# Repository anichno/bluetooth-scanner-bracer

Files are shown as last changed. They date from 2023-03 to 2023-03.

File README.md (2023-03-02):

# Docs
[Design Overview](docs/Design%20Overview.md)

[System Architecture](docs/System%20Architecture.md)

[Part List](docs/Part%20List.md)

[Milestones](docs/Milestones.md)

[Library Selection](docs/Library%20Selection.md)

[Links](docs/Links.md)

# Setup
- Setup vagrant (Virtualbox Provider)
	```bash
	# go grab a coffee or whatever, this will take a while
	vagrant up
	
	# get ssh-config and add it to your own
	vagrant ssh-config
	```
- Connect with VS Code, [remote-ssh](https://marketplace.visualstudio.com/items?itemName=ms-vscode-remote.remote-ssh) plugin
- Workspace will be in `/home/vagrant/project`
- Connect ESP32-S3-DevKitC, it should be auto-captured by Virtualbox

# Simulation
- Setup Wokwi VS Code Extension: https://docs.wokwi.com/vscode/getting-started
- Run 
	```bash
	makers simulate
	```
- `F1` -> Wokwi: Start Simulator

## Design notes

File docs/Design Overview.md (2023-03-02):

# Overview
Device will continually scan for nearby bluetooth devices. On discovery of a device, first it will check if it has been seen before and then retrieve the saved color for it. If it has not been seen before, a random color will be generated for it and will be saved.

For each visible device, a signal strength bar will be shown on the led strip. Position of the bar is:
 - random, but is "sticky" once assigned (until that device is no longer visible/too weak to show, it will remain in roughly the same position on the bracer)
 - based on signal strength (and can continually update)
Signal strength bars will be vertically expanded to use up "most" of the available lights. Position preference is based on switch input.

If the device sees a "paired" device, it will use its saved color, but position its signal strength bar at a known fixed location. It will then ping that device at an increased rate to improve its update resolution.

If scan resolution is slow, device will attempt to interpolate results such that the bars always expand and reposition in a smooth fashion. All updates will use a "fade" transition.

# Controls
- 2 buttons for brightness controls
- switch for signal strength ordering

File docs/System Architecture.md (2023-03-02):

```mermaid
flowchart LR
	micro[Microcontroller] --> lvl[Level Shifter]
	adj[Btn or Pot brightness] <--> micro
	lvl --> led[Led Strip]
	bat[Battery] --> led
	bat --> micro
	pos[Position Strategy Switch] --> micro
```

# Tasks
- scan for devices
- check for inputs
- update lights

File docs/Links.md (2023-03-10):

# Useful Links
- [Jtag Debugging esp32-s3](https://docs.espressif.com/projects/esp-idf/en/latest/esp32s3/api-guides/jtag-debugging/index.html)
	- https://esp-rs.github.io/book/tooling/debugging/vscode-debugging.html
- [esp32 Book](https://esp-rs.github.io/book/introduction.html)
- [Battery Life Calculator](https://www.digikey.com/en/resources/conversion-calculators/conversion-calculator-battery-life)
- [ESP32-S3-DevKitC](https://docs.espressif.com/projects/esp-idf/en/latest/esp32s3/hw-reference/esp32s3/user-guide-devkitc-1.html)
- https://docs.espressif.com/projects/esp-idf/en/latest/esp32/api-reference/kconfig.html
- https://github.com/cat-in-136/ws2812-esp32-rmt-driver/blob/main/examples/m5atom_smart_leds.rs
- https://github.com/espressif/kicad-libraries
- https://codepen.io/HunorMarton/details/eWvewo

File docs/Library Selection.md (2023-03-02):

# [esp32-nimble](https://crates.io/crates/esp32-nimble)
	Provides bluetooth scanning

# [ws2812-esp32-rmt-driver](https://crates.io/crates/ws2812-esp32-rmt-driver)
	esp32 driver for NeoPixels

# [smart-leds](https://crates.io/crates/smart-leds)
	common lib for NeoPixels

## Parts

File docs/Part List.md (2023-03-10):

# BOM
| Part | Price | Link |
| - | - | - |
| ESP32­-S3­-DevKitC-1 - ESP32-S3-WROOM-2 - 32MB Flash 8MB PSRAM | 19.95 | https://www.adafruit.com/product/5364 |
| 74AHCT125 - Quad Level-Shifter | 1.50 | https://www.adafruit.com/product/1787 |
| Adafruit NeoPixel Digital RGB LED Strip - Black 60 LED - BLACK | 24.95 | https://www.adafruit.com/product/1461?length=1 |
| Miady 2-Pack Portable Charger 5000mAh, 3.45oz Lightweight Power Bank, 5V/2.4A Output | 17.99 | https://www.amazon.com/Miady-Portable-Charger-5000mAh-Lightweight/dp/B083VRD7CX |
| Breadboard-friendly SPDT Slide Switch | 0.95 | https://www.adafruit.com/product/805 |
| Dual Micro USB Charging Cable USB to Micro USB Splitter Adapter, 2 pack | 9.99 | https://www.amazon.com/UCEC-Splitter-Charge-Devices-Single/dp/B0179OXY9I |
|  Micro USB to DIP Adapter 5pin Female Connector B Type, 10 pack | 5.89 | https://www.amazon.com/gp/product/B07W844N43 |
|  Tactile Button switch (6mm) x 20 pack | 2.50 | https://www.adafruit.com/product/367 |

https://www.academy.com/p/game-on-adults-compression-arm-sleeve

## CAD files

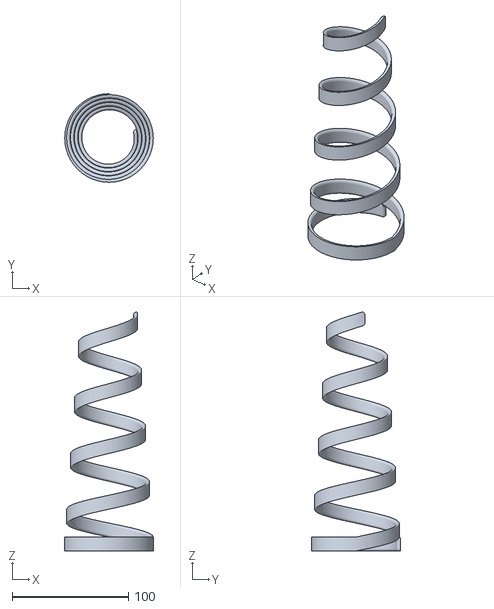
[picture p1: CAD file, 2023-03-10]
models/bluetooth_scanner_bracer v2.stl
76.1 x 76.1 x 205.3

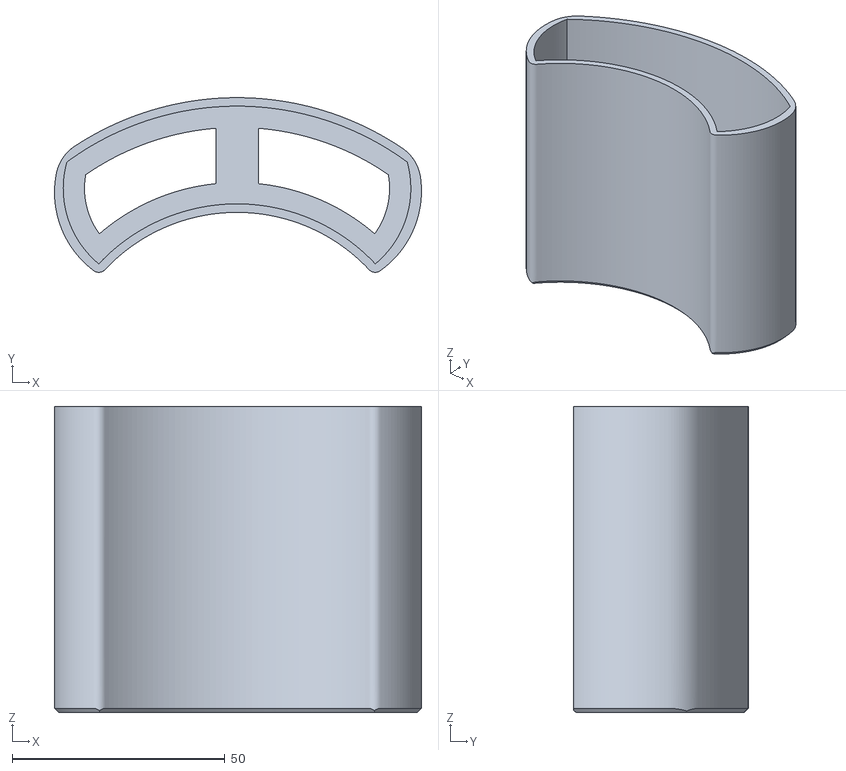
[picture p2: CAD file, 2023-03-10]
models/bluetooth_scanner_electronics_box v4.stl
86.3 x 41.1 x 72.0

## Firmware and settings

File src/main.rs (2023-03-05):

//! Runtime tasks:
//! - BLE scan
//! - LED control
//! - BLE decay
//! - Input monitor
//! - TODO: interpolate device signal strength
//!
//! TODO: Remove floating point math

#![warn(clippy::disallowed_macros)]

use std::sync::Arc;

use esp_idf_sys as _;
use log::*;
use std::sync::Mutex;

mod ble_device_mgr;
mod led_strip;
mod light_mgr;
mod messages;
mod tasks;
mod utils;

fn main() {
    // It is necessary to call this function once. Otherwise some patches to the runtime
    // implemented by esp-idf-sys might not link properly. See https://github.com/esp-rs/esp-idf-template/issues/71
    esp_idf_sys::link_patches();

    esp_idf_svc::log::EspLogger::initialize_default();
    log::set_max_level(log::LevelFilter::Debug);

    #[allow(clippy::needless_update)]
    {
        esp_idf_sys::esp!(unsafe {
            esp_idf_sys::esp_vfs_eventfd_register(&esp_idf_sys::esp_vfs_eventfd_config_t {
                max_fds: 5,
                ..Default::default()
            })
        })
        .unwrap();
    }

    let device_mgr = Arc::new(Mutex::new(ble_device_mgr::DeviceTracker::new()));

    let (light_controls_chan_tx, light_controls_chan_rx) = smol::channel::bounded(1);

    // Separate thread for tighter timing
    let led_animate_device_mgr = device_mgr.clone();
    std::thread::spawn(move || tasks::led_animator(led_animate_device_mgr, light_controls_chan_rx));

    smol::block_on(async {
        info!("Starting BLE scanner task");
        let ble_scan_task = smol::spawn(tasks::ble_scanner(device_mgr.clone()));
        let ble_decayer_task = smol::spawn(tasks::ble_device_decayer(device_mgr.clone()));
        let button_monitor_task = smol::spawn(tasks::button_monitor(light_controls_chan_tx));

        futures::future::select_all([ble_scan_task, ble_decayer_task, button_monitor_task]).await;
        error!("One of the tasks has exited unexpectedly. Exiting...")
    });

    info!("END");
}

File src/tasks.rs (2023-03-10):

use std::sync::Arc;

use esp_idf_hal::{
    gpio::{PinDriver, Pull},
    prelude::Peripherals,
};
use log::*;
use smol::stream::StreamExt;
use std::sync::Mutex;

const DEBOUNCE_TIME_MS: u64 = 5;

#[cfg(not(feature = "simulator"))]
pub async fn ble_scanner(device_mgr: Arc<Mutex<crate::ble_device_mgr::DeviceTracker>>) {
    use esp32_nimble::BLEDevice;

    let ble_device = BLEDevice::take();

    // Set up advertising
    ble_device
        .get_advertising()
        .name(const_format::concatcp!(
            crate::ble_device_mgr::FAVORITE_DEVICE_ID,
            ':',
            env!("FAVORITE_COLOR")
        ))
        .scan_response(true)
        .start()
        .unwrap();

    // Set up scanning
    let ble_scan = ble_device.get_scan();
    let scanner = ble_scan
        .active_scan(true)
        .interval(40)
        .window(30)
        .filter_duplicates(true);

    loop {
        let device_mgr = device_mgr.clone();

        scanner
            .on_result(move |scan_result| {
                #[cfg(feature = "debug")]
                info!(
                    "Scan result: {{name: {}, addr: {}, rssi: {}}}",
                    scan_result.name(),
                    scan_result.addr(),
                    scan_result.rssi()
                );
                device_mgr.lock().unwrap().update(
                    *scan_result.addr(),
                    scan_result.name(),
                    scan_result.rssi(),
                );
            })
            .start(100)
            .await
            .unwrap();
        scanner.clear_results();
    }
}

#[cfg(feature = "simulator")]
pub async fn ble_scanner(device_mgr: Arc<Mutex<crate::ble_device_mgr::DeviceTracker>>) {
    use const_format::concatcp;

    let mut first_update = true;

    loop {
        let do_update = device_mgr.lock().unwrap().devices.is_empty();
        if do_update {
            if !first_update {
                smol::Timer::after(std::time::Duration::from_millis(5000)).await;
            }
            first_update = false;
            let mut device_mgr = device_mgr.lock().unwrap();
            // add fake devices
            for i in 0..10 {
                device_mgr.update(
                    esp32_nimble::BLEAddress::new_from_addr([i, 0x22, 0x33, 0x44, 0x55, 0x66]),
                    "",
                    -50 - i as i32 * 2,
                );
            }

            // add fake favorite device
            device_mgr.update(
                esp32_nimble::BLEAddress::new_from_addr([0x11, 0x22, 0x33, 0x44, 0x55, 0x66]),
                concatcp!(crate::ble_device_mgr::FAVORITE_DEVICE_ID, ":0"),
                -50,
            );
        }

        smol::Timer::after(std::time::Duration::from_millis(100)).await;
    }
}

pub fn led_animator(
    device_mgr: Arc<Mutex<crate::ble_device_mgr::DeviceTracker>>,
    light_controls_chan: smol::channel::Receiver<crate::messages::LightControls>,
) {
    let mut light_manager =
        crate::light_mgr::LightMgr::new(device_mgr, crate::messages::DisplaySortMode::Ordered);
    let interval = light_manager.get_tick_interval();

    loop {
        let start = std::time::Instant::now();
        match light_controls_chan.try_recv() {
            Ok(msg) => {
                info!("Received control message: {:?}", msg);
                match msg {
                    crate::messages::LightControls::BrightnessIncrease => {
                        light_manager.increase_brightness()
                    }
                    crate::messages::LightControls::BrightnessDecrease => {
                        light_manager.decrease_brightness()
                    }
                    crate::messages::LightControls::ModeChange(new_mode) => {
                        light_manager.switch_mode(new_mode)
                    }
                }
            }
            Err(err) => match err {
                smol::channel::TryRecvError::Empty => {} // no message, do nothing
                smol::channel::TryRecvError::Closed => {
                    info!("Light controls channel closed, exiting");
                    return;
                }
            },
        }
        light_manager.tick();
        let wait_time = interval.saturating_sub(start.elapsed());
        std::thread::sleep(wait_time);
    }
}

pub async fn ble_device_decayer(device_mgr: Arc<Mutex<crate::ble_device_mgr::DeviceTracker>>) {
    let mut update_timer = smol::Timer::interval(std::time::Duration::from_secs(1));
    loop {
        info!("Decaying devices");
        device_mgr.lock().unwrap().decay_tick();
        update_timer.next().await;
    }
}

/// Monitor for button presses and the toggle switches
/// Using polling for now, but could be changed to interrupt based
pub async fn button_monitor(
    light_controls_chan: smol::channel::Sender<crate::messages::LightControls>,
) {
    async fn wait_stable_low<T: esp_idf_hal::gpio::Pin, MODE: esp_idf_hal::gpio::InputMode>(
        pin: PinDriver<'_, T, MODE>,
    ) -> PinDriver<'_, T, MODE> {
        smol::Timer::after(std::time::Duration::from_millis(DEBOUNCE_TIME_MS)).await;
        while pin.is_high() {
            smol::Timer::after(std::time::Duration::from_millis(10)).await;
        }
        let mut last_state = pin.is_high();
        let mut last_state_change =
            smol::Timer::after(std::time::Duration::from_millis(DEBOUNCE_TIME_MS)).await;
        loop {
            let current_state = pin.is_high();
            if current_state != last_state {
                last_state = current_state;
                last_state_change =
                    smol::Timer::after(std::time::Duration::from_millis(DEBOUNCE_TIME_MS)).await;
            }
            if last_state_change.elapsed() > std::time::Duration::from_millis(DEBOUNCE_TIME_MS) {
                return pin;
            }
        }
    }
    enum SwitchPosition {
        /// LOW
        Left,

        /// HIGH
        Right,
    }

    let peripherals = Peripherals::take().unwrap();
    let gpio_pins = peripherals.pins;

    let mut btn_brightness_increase = PinDriver::input(gpio_pins.gpio13).unwrap();
    btn_brightness_increase.set_pull(Pull::Down).unwrap();

    let mut btn_brightness_decrease = PinDriver::input(gpio_pins.gpio12).unwrap();
    btn_brightness_decrease.set_pull(Pull::Down).unwrap();

    // let mut switch_display_mode = PinDriver::input(gpio_pins.gpio36).unwrap();
    let mut switch_display_mode = PinDriver::input(gpio_pins.gpio15).unwrap();
    switch_display_mode.set_pull(Pull::Down).unwrap();

    // get switch initial state
    let mut switch_display_last_position = if switch_display_mode.is_high() {
        SwitchPosition::Right
    } else {
        SwitchPosition::Left
    };
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

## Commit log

2023-03-03 simulator devices re added after they decay
2023-03-05 switch to faster led strip implementation
2023-03-05 timing fixes for lights
    [led_strip.rs]
2023-03-07 switch to hsv color space
2023-03-10 improved brightness buttons and brightness levels
2023-03-10 added pcb schematic and 3d models
    [bluetooth-scanner-bracer.kicad_sch, bluetooth_scanner_bracer v2.stl, bluetooth_scanner_electronics_box v4.stl]
